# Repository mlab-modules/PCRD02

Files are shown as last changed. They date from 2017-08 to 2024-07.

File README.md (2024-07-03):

# PCRD - Plocs Cosmic Ray Detector

The PCRD is a semiconductor detector for cosmic rays. Its main advantages include sensitivity to all charged particles, low energy consumption, and low weight. Additionally, if the interaction with radiation transfers all its energy to the silicon, it is possible to determine the energy spectrum of the mixed radiation field.

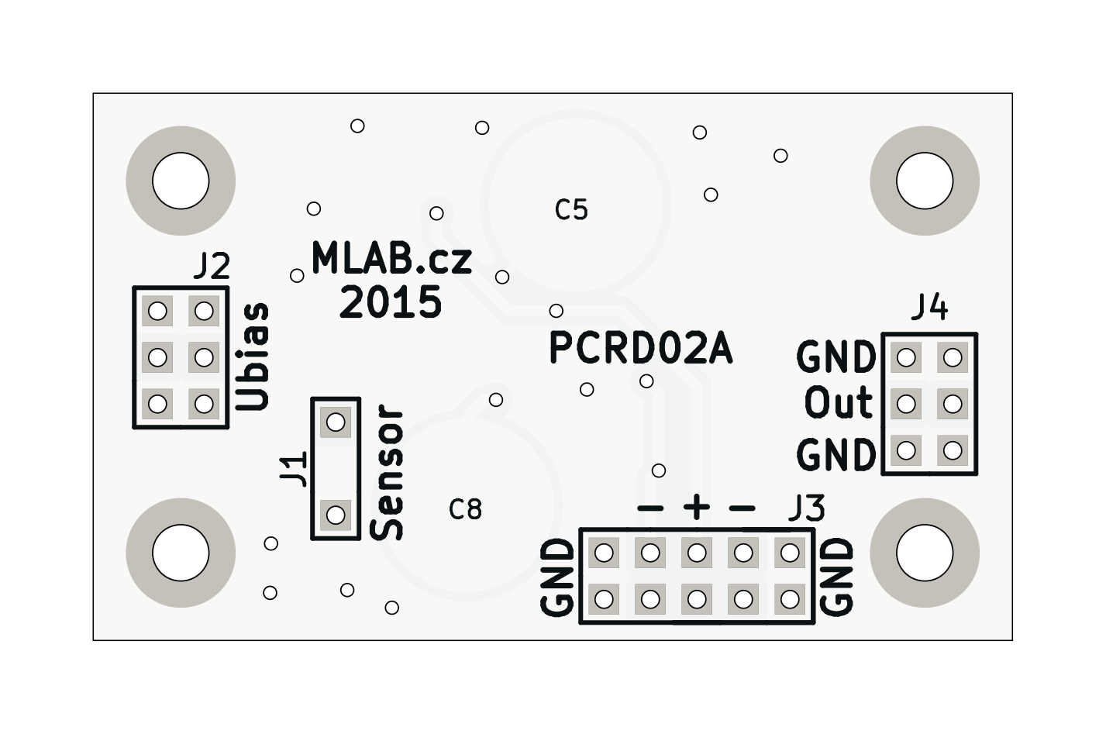
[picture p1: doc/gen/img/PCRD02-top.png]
PCRD02 top
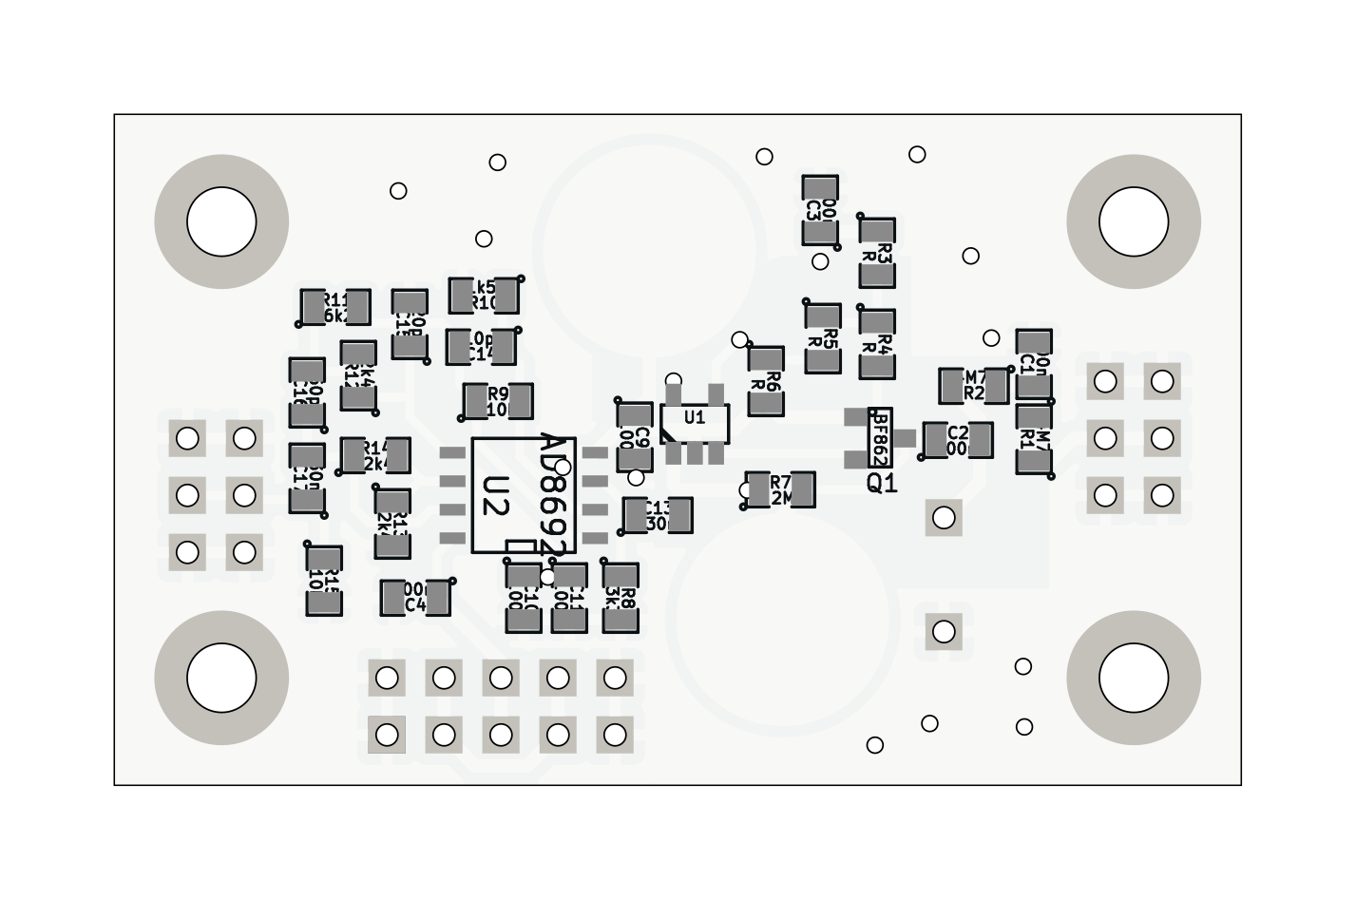
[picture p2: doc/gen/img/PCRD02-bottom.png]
PCRD02 bottom
 

## Technical Parameters

| **Parameter** | **Value** | **Note** |
|---|---|---|
| Power Supply  | +/- 2.4V | |
| Dimensions | 30.0 x 50.3 x 16 mm | Height above base board  |

## Construction Description

### Mechanical Construction

The module contains mounting screws in all corners with an MLAB pitch (10.16mm). If space-saving is needed, the part of the PCB with two screws can be broken off.

## Assembly and Commissioning

### Assembly

| **Designation** | **Type** | **Package** | **Quantity** |
|---|---|---|---|
| R7 | 2M | SMD-0805 | 1 |
| C1, C2 | 100nF | SMD-0805 | 2 |
| C3, C4, C9, C10, C11 | 100n | SMD-0805 | 5 |
| C13, C17 | 330nF | SMD-0805 | 2 |
| C14 | 510pF | SMD-0805 | 1 |
| C15 | 220pF | SMD-0805 | 1 |
| C16 | 150pF | SMD-0805 | 1 |
| J2 | JUMP_3X2 | Pin_Header_Straight_2x03 | 1 |
| J3 | JUMP_5X2 | Pin_Header_Straight_2x05 | 1 |
| J4 | Out | Pin_Header_Straight_2x03 | 1 |
| P1, P2, P3, P4  | _ | MountingHole_3mm | 4 |
| Q1 | BF862 | SOT-23 | 1 |
| R1, R2 | 4M7 | SMD-0805 | 2 |
| R8 | 3k3 | SMD-0805 | 1 |
| R9, R15 | 10k | SMD-0805 | 2 |
| R10 | 1k5 | SMD-0805 | 1 |
| R11 | 6k2 | SMD-0805 | 1 |
| R12, R13, R14 | 2k41k | SMD-0805 | 3 |
| U1 | AD8691 | tsot-5 | 1 |
| J1 | CONN1_2 | CONN_3_2 | 1 |
| U2 | AD8692 | SOIC-8-N | 1 |
| C5, C8 | 2pF | 2pF_PCB | 2 |
| **Variant 1** | | | |
| R3 | 1k | SMD-0805 | 1 |
| R4 | 62 | SMD-0805 | 1 |
| R5 | 100 | SMD-0805 | 1 |
| R6 | 2k | SMD-0805 | 1 |
| **Variant 2** | | | |
| R3 | 1k | SMD-0805 | 1 |
| R4 | 300 | SMD-0805 | 1 |
| R5 | 430 | SMD-0805 | 1 |
| R6 | 1k | SMD-0805 | 1 |

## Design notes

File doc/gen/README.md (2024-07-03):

# PCB

Board size: 50.29x29.97 mm (1.98x1.18 inches)

- This is the size of the rectangle that contains the board
- Thickness: 1.6 mm (63 mils)
- Material: FR4
- Finish: HAL
- Layers: 2
- Copper thickness: 35 µm

Solder mask: TOP / BOTTOM

- Color: Green

Silk screen: TOP / BOTTOM

- Color: White

# Important sizes

Clearance: 0.25 mm (10 mils)

Track width: 0.4 mm (16 mils)

- By design rules: 0.25 mm (10 mils)

Drill: 0.75 mm (30 mils)

- Vias: 0.75 mm (30 mils) [Design: 0.6 mm (24 mils)]
- Pads: 1.0 mm (39 mils)
- The above values are real drill sizes, they add 0.1 mm (4 mils) to plated holes (PTH)

Via: 0.89/0.64 mm (35/25 mils)

- By design rules: 0.89/0.51 mm (35/20 mils)
- Micro via: yes [0.51/0.13 mm (20/5 mils)]
- Buried/blind via: yes
- Total: 18 (thru: 18 buried/blind: 0 micro: 0)

Outer Annular Ring: 0.07 mm (3 mils)

- By design rules: 0.33 mm (13 mils)

Eurocircuits class: 10A
- Using min drill 0.75 mm for an OAR of 0.07 mm

# General stats

Components count: (SMD/THT)

- Top: 0/10 (THT)
- Bottom: 29/1 (SMD + THT)

Defined tracks:

- 0.26 mm (10 mils)
- 0.4 mm (16 mils)
- 0.6 mm (24 mils)

Used tracks:

- 0.4 mm (16 mils) (110) defined: yes
- 0.6 mm (24 mils) (75) defined: yes

Defined vias:

Used vias:

- 0.89/0.64 mm (35/25 mils) (Count: 18, Aspect: 1.8 A) defined: no

Holes (excluding vias):

- 0.9 mm (35 mils) (24)
- 3.0 mm (118 mils) (4)

Oval holes:

Drill tools (including vias and computing adjusts and rounding):

- 0.75 mm (30 mils) (18)
- 1.0 mm (39 mils) (24)
- 3.1 mm (122 mils) (4)

Solder paste stats:

Using a paste with 87.75 % alloy, that has an specific gravity for the alloy of 7.4 g/cm³
and 1.0 g/cm³ for the flux. This paste has an specific gravity of  4.15 g/cm³.

The stencil thickness is  0.12 mm.

| Side | Pads with paste | Area [mm²] | Paste [g] |
|---|---|---|---|
| Total  | 70 | 77.57 | 0.39 |

Note: this is just an approximation to the theoretical value. Margins of the solder mask and waste aren't computed.

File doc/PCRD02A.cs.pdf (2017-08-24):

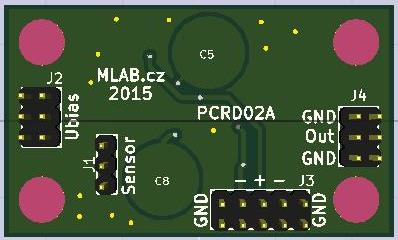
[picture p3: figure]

PCRD02A / 2016-03-09 / jacho/ http://www.mlab.cz | 1 / 5
PCRD02A | MLAB

# Zesilovač pro detektor

## Plocs cosmic ray detector (PCRD)

# 1. Technické parametry

Parametr | Hodnota | Poznámka
Napájení | +/- 2,4 V
Rozměry | 30.0 x 50.3 x 16 mm | Výška nad základní deskou

PCRD02A | MLAB

# 2. Popis konstrukce

## 2.1. Úvodem

## 2.2. Mechanická konstrukce

Modul obsahuje úchytné šroubky ve všech rozích v rozteči MLAB (10.16mm). Při potřebě šetřit místem je možné odlomení části PCB se dvěma šrouby.

PCRD02A | MLAB

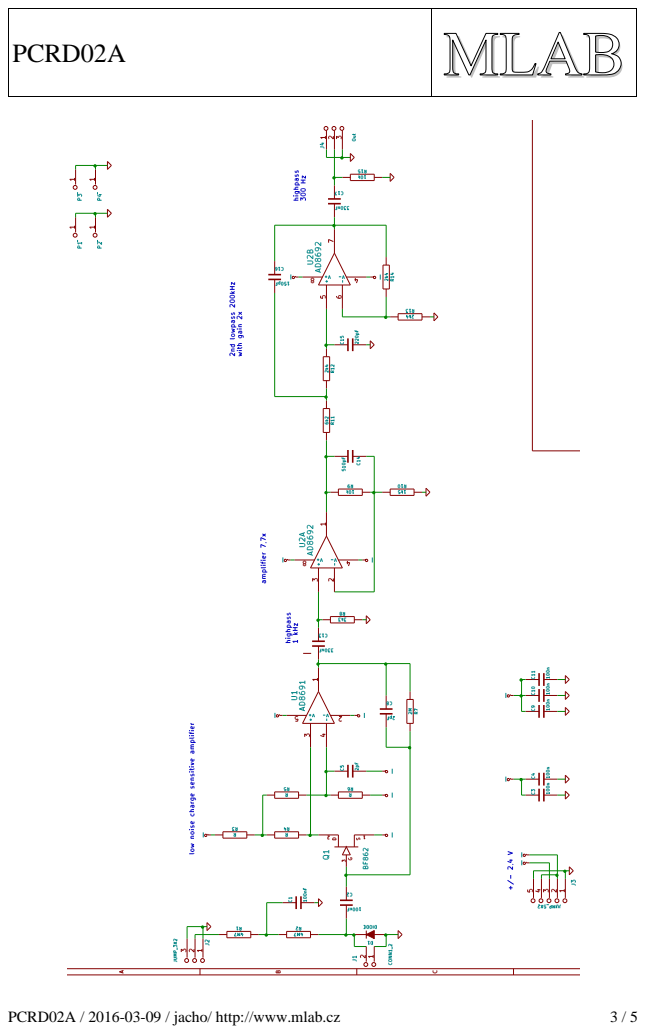
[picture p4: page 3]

PCRD02A | MLAB

# 3. Osazení a oživení

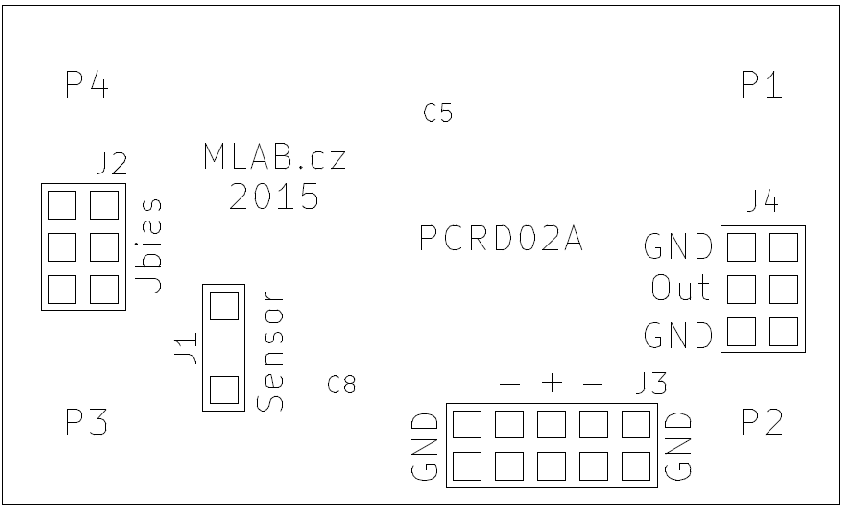
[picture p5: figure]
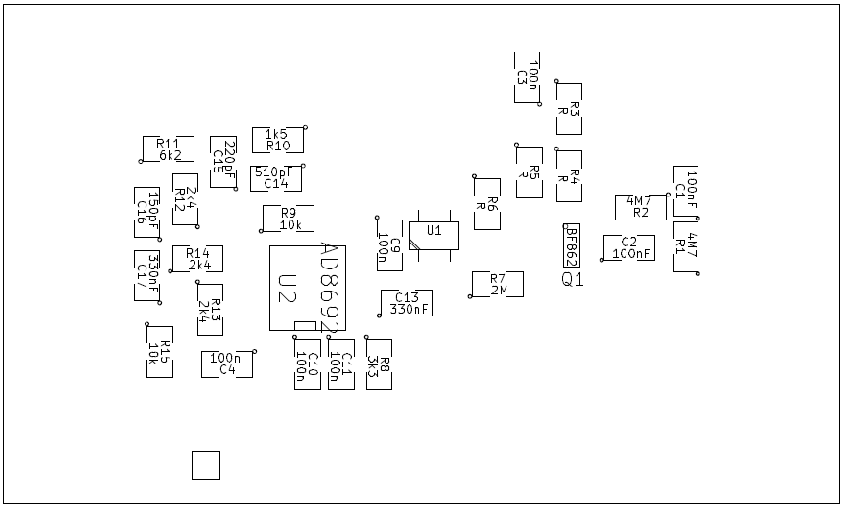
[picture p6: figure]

PCRD02A | MLAB

## 3.1. Osazení

Označení | Typ | Pouzdro | Počet
R7 | 2M | SMD-0805 | 1
C1,C2 | 100nF | SMD-0805 | 2
C3,C4,C9,C10,C11 | 100n | SMD-0805 | 5
C13,C17 | 330nF | SMD-0805 | 2
C14 | 510pF | SMD-0805 | 1
C15 | 220pF | SMD-0805 | 1
C16 | 150pF | SMD-0805 | 1
J2 | JUMP_3X2 | Pin_Header_Straight_2x03 | 1
J3 | JUMP_5X2 | Pin_Header_Straight_2x05 | 1
J4 | Out | Pin_Header_Straight_2x03 | 1
P1,P2,P3,P4 | _ | MountingHole_3mm | 4
Q1 | BF862 | SOT-23 | 1
R1,R2 | 4M7 | SMD-0805 | 2
R8 | 3k3 | SMD-0805 | 1
R9,R15 | 10k | SMD-0805 | 2
R10 | 1k5 | SMD-0805 | 1
R11 | 6k2 | SMD-0805 | 1
R12,R13,R14 | 2k4 | SMD-0805 | 3
U1 | AD8691 | tsot-5 | 1
J1 | CONN1_2 | CONN_3_2 | 1
U2 | AD8692 | SOIC-8-N | 1
C5,C8 | 2pF | 2pF_PCB | 2

Varianta 1
R3 | 1k | SMD-0805 | 1
R4 | 62 | SMD-0805 | 1
R5 | 100 | SMD-0805 | 1
R6 | 2k | SMD-0805 | 1

Varianta 2
R3 | 1k | SMD-0805 | 1
R4 | 300 | SMD-0805 | 1
R5 | 430 | SMD-0805 | 1
R6 | 1k | SMD-0805 | 1

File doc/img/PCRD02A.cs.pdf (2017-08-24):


PCRD02A / 2015-04-02 / jacho/ http://www.mlab.cz | 1 / 5
PCRD02A | MLAB

# Zesilovač pro detektor

## Plocs cosmic ray detector (PCRD)

# 1. Technické parametry

Parametr | Hodnota | Poznámka
Napájení | +/- 2,4 V
Rozměry | 30.0 x 50.3 x 16 mm | Výška nad základní deskou

PCRD02A | MLAB

# 2. Popis konstrukce

## 2.1. Úvodem

## 2.2. Mechanická konstrukce

Modul obsahuje úchytné šroubky ve všech rozích v rozteči MLAB (10.16mm). Při potřebě šetřit místem je možné odlomení části PCB se dvěma šrouby.

PCRD02A | MLAB

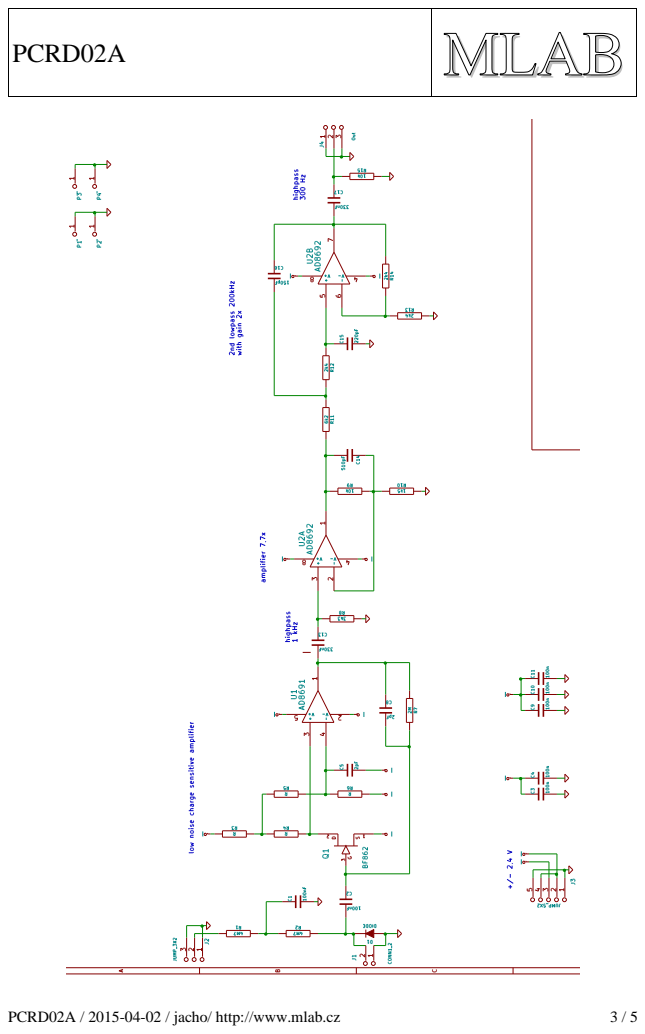
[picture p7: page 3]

PCRD02A | MLAB

# 3. Osazení a oživení

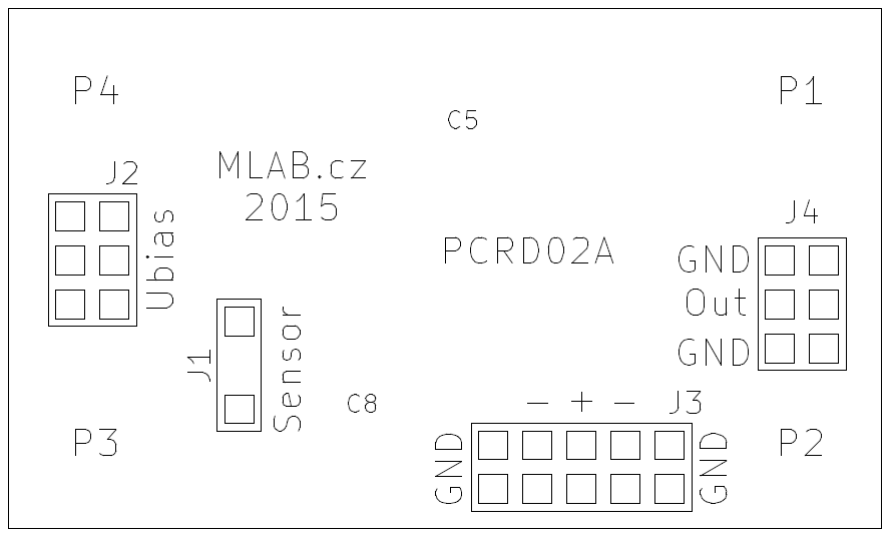
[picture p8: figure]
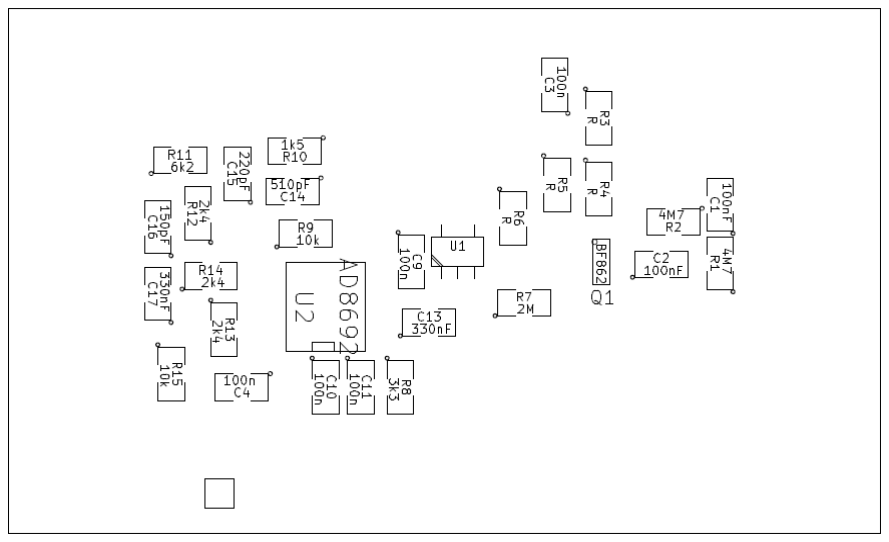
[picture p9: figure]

PCRD02A | MLAB

## 3.1. Osazení

Označení | Typ | Pouzdro | Počet
R7 | 2M | SMD-0805 | 1
C1,C2 | 100nF | SMD-0805 | 2
C3,C4,C9,C10,C11 | 100n | SMD-0805 | 5
C13,C17 | 330nF | SMD-0805 | 2
C14 | 510pF | SMD-0805 | 1
C15 | 220pF | SMD-0805 | 1
C16 | 150pF | SMD-0805 | 1
J2 | JUMP_3X2 | Pin_Header_Straight_2x03 | 1
J3 | JUMP_5X2 | Pin_Header_Straight_2x05 | 1
J4 | Out | Pin_Header_Straight_2x03 | 1
P1,P2,P3,P4 | _ | MountingHole_3mm | 4
Q1 | BF862 | SOT-23 | 1
R1,R2 | 4M7 | SMD-0805 | 2
R8 | 3k3 | SMD-0805 | 1
R9,R15 | 10k | SMD-0805 | 2
R10 | 1k5 | SMD-0805 | 1
R11 | 6k2 | SMD-0805 | 1
R12,R13,R14 | 2k4 | SMD-0805 | 3
U1 | AD8691 | tsot-5 | 1
J1 | CONN1_2 | CONN_3_2 | 1
U2 | AD8692 | SOIC-8-N | 1
C5,C8 | 2pF | 2pF_PCB | 2

Varianta 1
R3 | 1k | SMD-0805 | 1
R4 | 62 | SMD-0805 | 1
R5 | 100 | SMD-0805 | 1
R6 | 2k | SMD-0805 | 1

Varianta 2
R3 | 1k | SMD-0805 | 1
R4 | 300 | SMD-0805 | 1
R5 | 430 | SMD-0805 | 1
R6 | 1k | SMD-0805 | 1

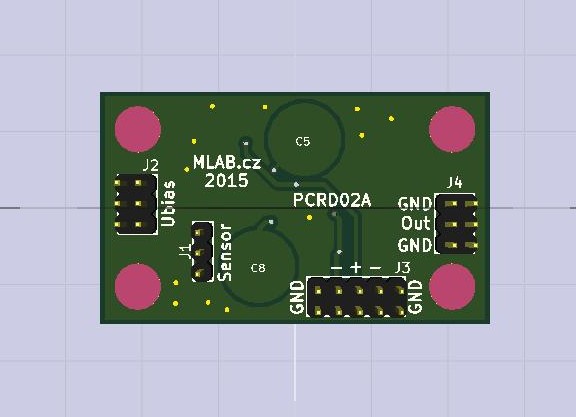
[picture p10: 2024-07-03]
doc/img/PCRD02A_top_small.jpg

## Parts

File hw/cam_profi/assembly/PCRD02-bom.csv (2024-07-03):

Component | Description | Part | References | Value | Footprint | Quantity Per PCB | Datasheet
1 |  | C | C5C8 | 2pF | C2pF | 2
2 |  | C | C16 | 150pF | SMD-0805 | 1
3 |  | C | C15 | 220pF | SMD-0805 | 1
4 |  | C | C14 | 510pF | SMD-0805 | 1
5 |  | C | C1C2C3C4C9C10C11 | 100nF | SMD-0805 | 7
6 |  | C | C13C17 | 330nF | SMD-0805 | 2
7 |  | DIODE | D1 | DIODE |  | 1
8 |  | CONN1_2 | J1 | CONN1_2 | CONN_3_2 | 1
9 |  | JUMP_3X2 | J2 | JUMP_3X2 | Pin_Header_Straight_2x03 | 1
10 |  | JUMP_5X2 | J3 | JUMP_5X2 | Pin_Header_Straight_2x05 | 1
11 |  | JUMP_3X2 | J4 | Out | Pin_Header_Straight_2x03 | 1
12 |  | JFET_N | Q1 | BF862 | SOT-23 | 1
13 |  | R | R10 | 1k5 | SMD-0805 | 1
14 |  | R | R12R13R14 | 2k4 | SMD-0805 | 3
15 |  | R | R8 | 3k3 | SMD-0805 | 1
16 |  | R | R11 | 6k2 | SMD-0805 | 1
17 |  | R | R9R15 | 10k | SMD-0805 | 2
18 |  | R | R7 | 2M | SMD-0805 | 1
19 |  | R | R1R2 | 4M7 | SMD-0805 | 2
20 |  | R | R3R4R5R6 | R | SMD-0805 | 4
21 |  | AD8691 | U1 | AD8691 | tsot-5 | 1
22 |  | AD8692 | U2 | AD8692 | SOIC-8-N | 1

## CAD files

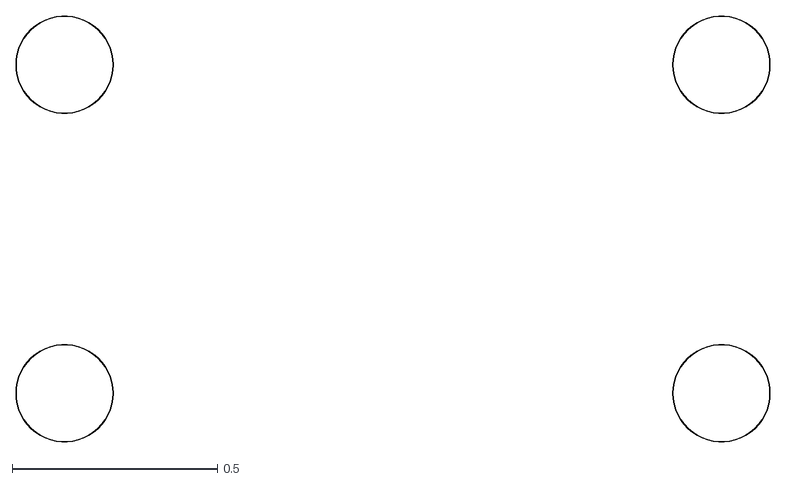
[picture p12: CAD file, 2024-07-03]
doc/gen/dxf/PCRD02-F_Adhesive.dxf
1.84 x 1.04

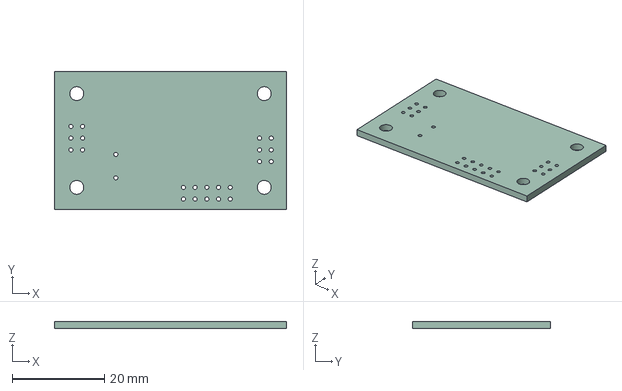
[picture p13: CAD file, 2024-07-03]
doc/gen/PCRD02.step
50.3 x 30.0 x 1.60 mm

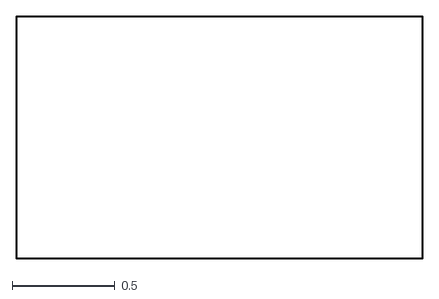
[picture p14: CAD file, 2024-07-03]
doc/gen/dxf/PCRD02-Edge_Cuts.dxf
1.98 x 1.18

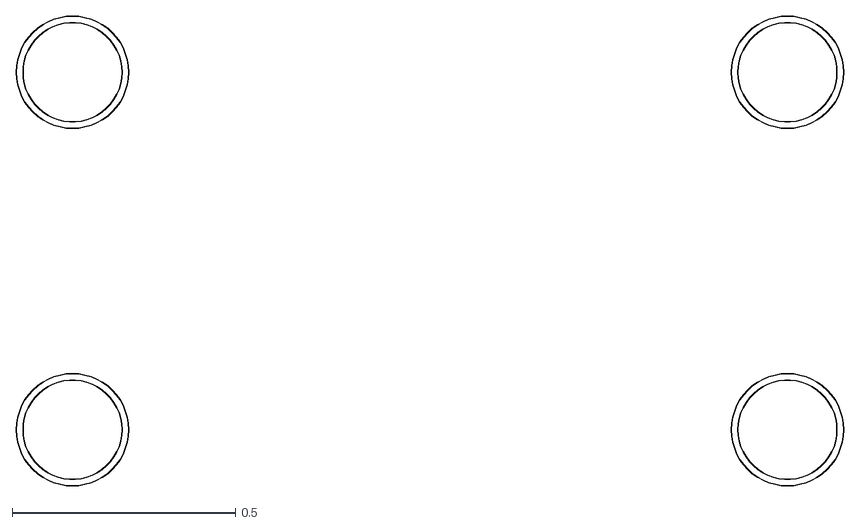
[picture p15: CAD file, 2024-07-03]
doc/gen/dxf/PCRD02-User_Comments.dxf
1.85 x 1.05

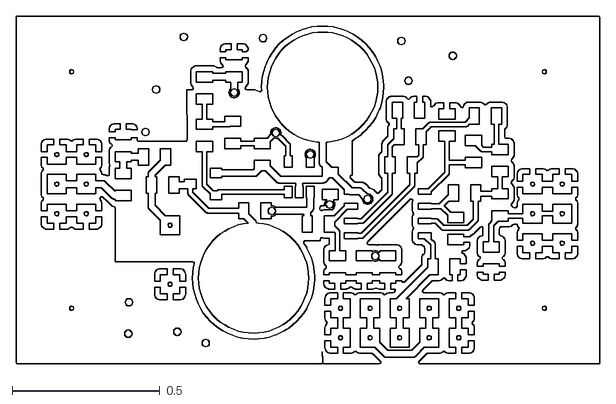
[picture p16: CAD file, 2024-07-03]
doc/gen/dxf/PCRD02-B_Cu.dxf
1.98 x 1.18

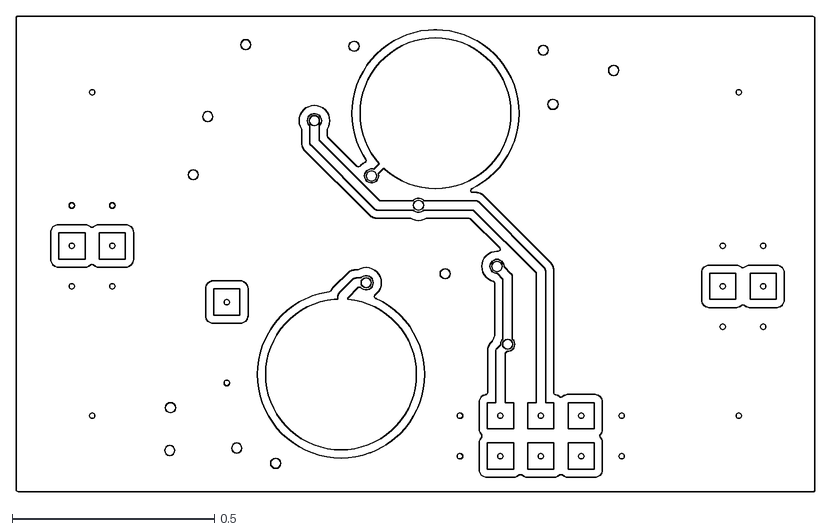
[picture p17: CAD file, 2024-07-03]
doc/gen/dxf/PCRD02-F_Cu.dxf
1.98 x 1.18

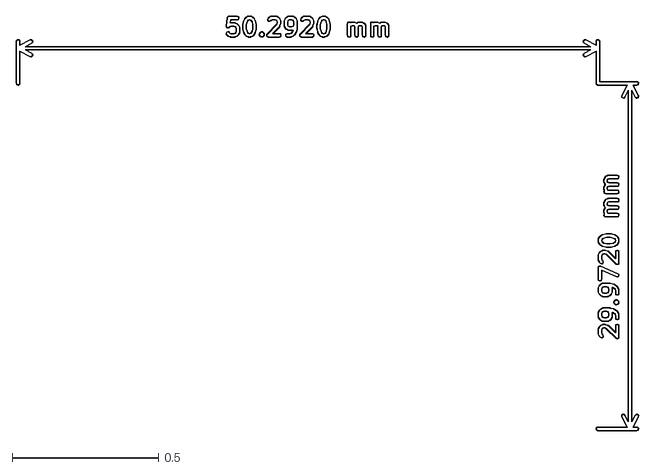
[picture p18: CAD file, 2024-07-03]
doc/gen/dxf/PCRD02-User_Drawings.dxf
2.12 x 1.42

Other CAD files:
doc/gen/dxf/PCRD02-F_Fab.dxf
doc/gen/dxf/PCRD02-Margin.dxf
doc/gen/dxf/PCRD02-F_Courtyard.dxf
doc/gen/dxf/PCRD02-B_Fab.dxf
doc/gen/dxf/PCRD02-User_Eco2.dxf
doc/gen/dxf/PCRD02-User_Eco1.dxf
doc/gen/dxf/PCRD02-B_Courtyard.dxf
doc/gen/dxf/PCRD02-B_Mask.dxf
doc/gen/dxf/PCRD02-B_Paste.dxf
doc/gen/dxf/PCRD02-B_Silkscreen.dxf
doc/gen/dxf/PCRD02-F_Mask.dxf
doc/gen/dxf/PCRD02-F_Paste.dxf
doc/gen/dxf/PCRD02-F_Silkscreen.dxf

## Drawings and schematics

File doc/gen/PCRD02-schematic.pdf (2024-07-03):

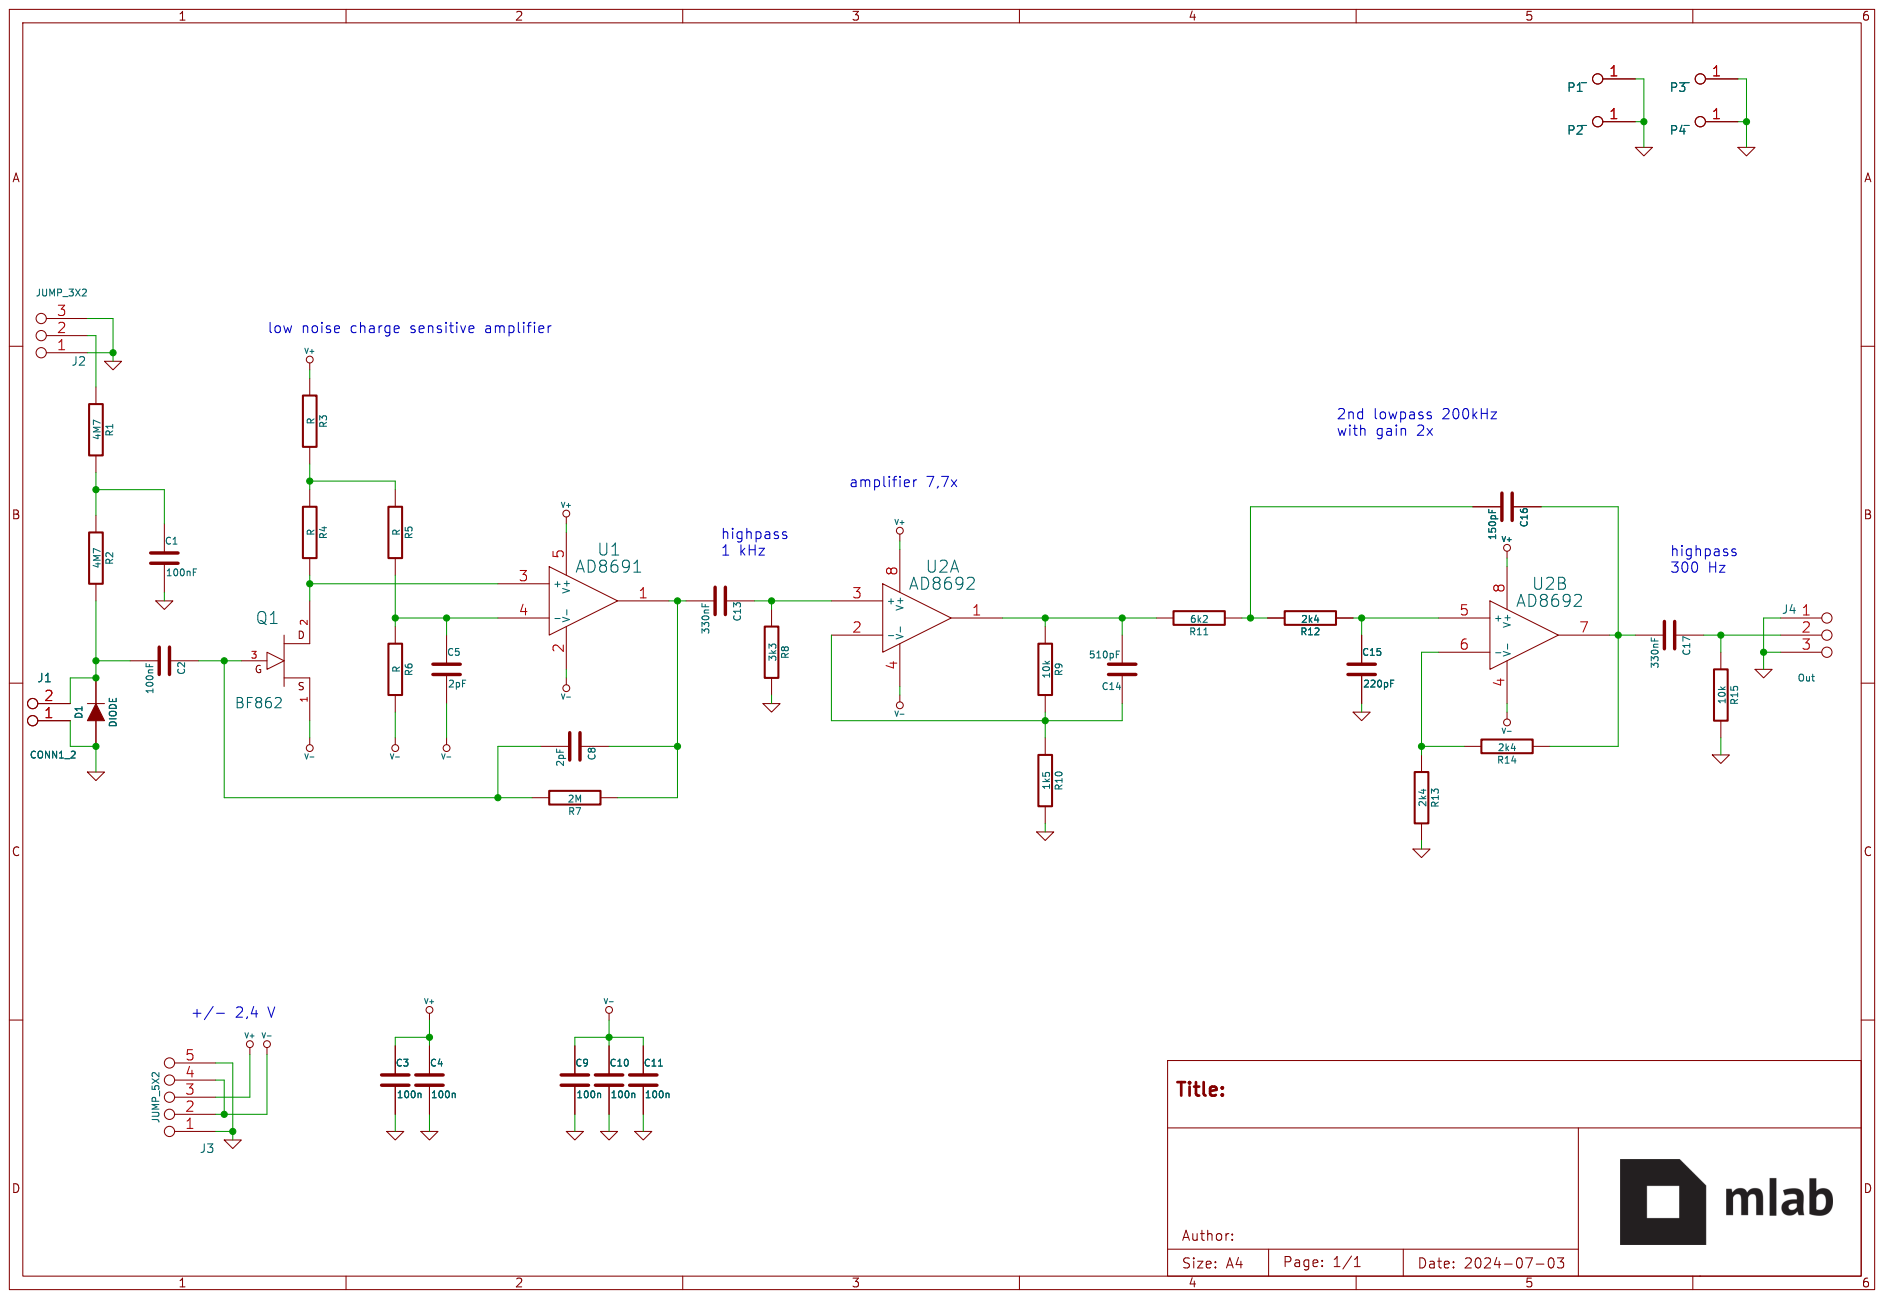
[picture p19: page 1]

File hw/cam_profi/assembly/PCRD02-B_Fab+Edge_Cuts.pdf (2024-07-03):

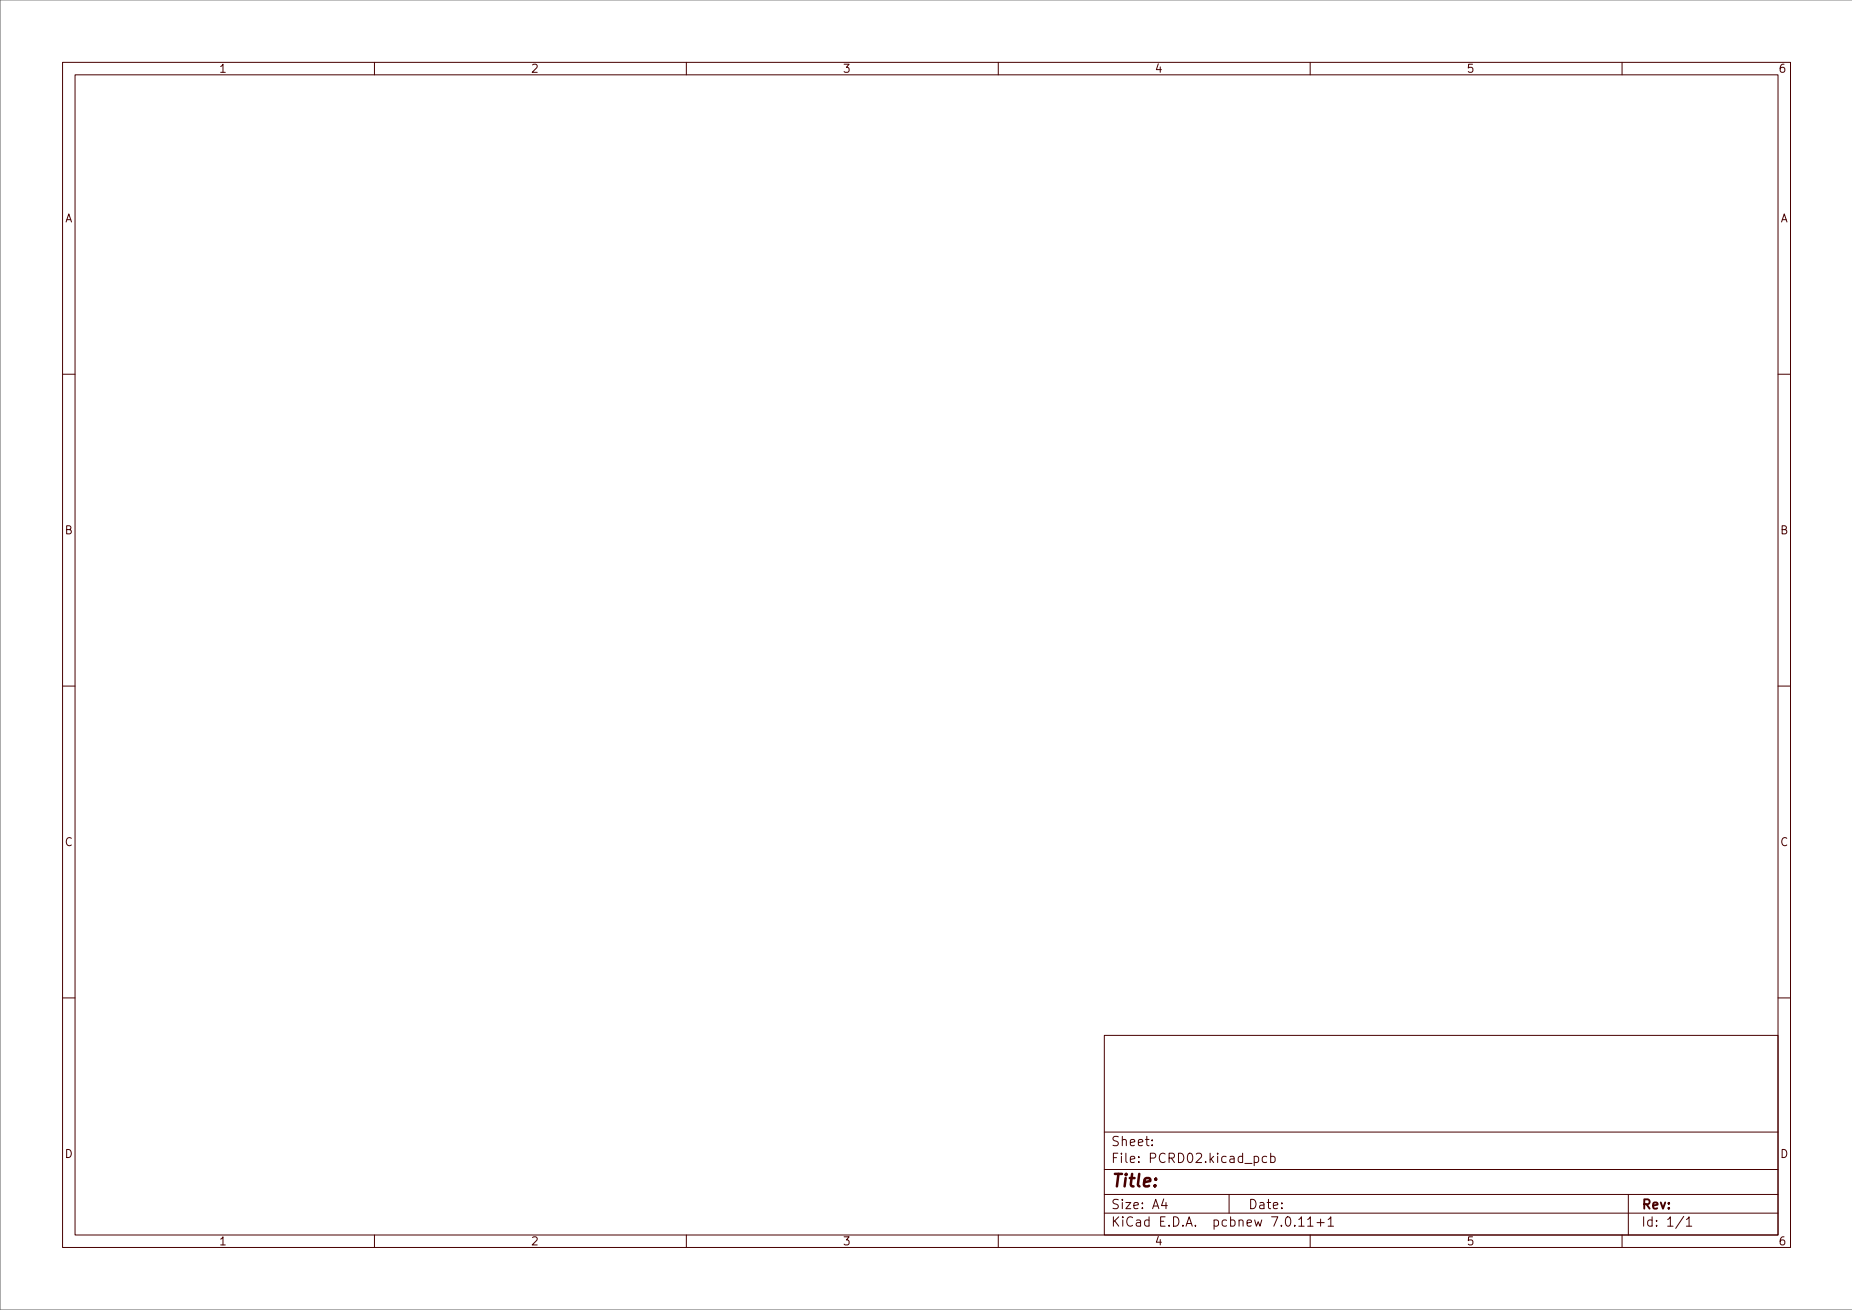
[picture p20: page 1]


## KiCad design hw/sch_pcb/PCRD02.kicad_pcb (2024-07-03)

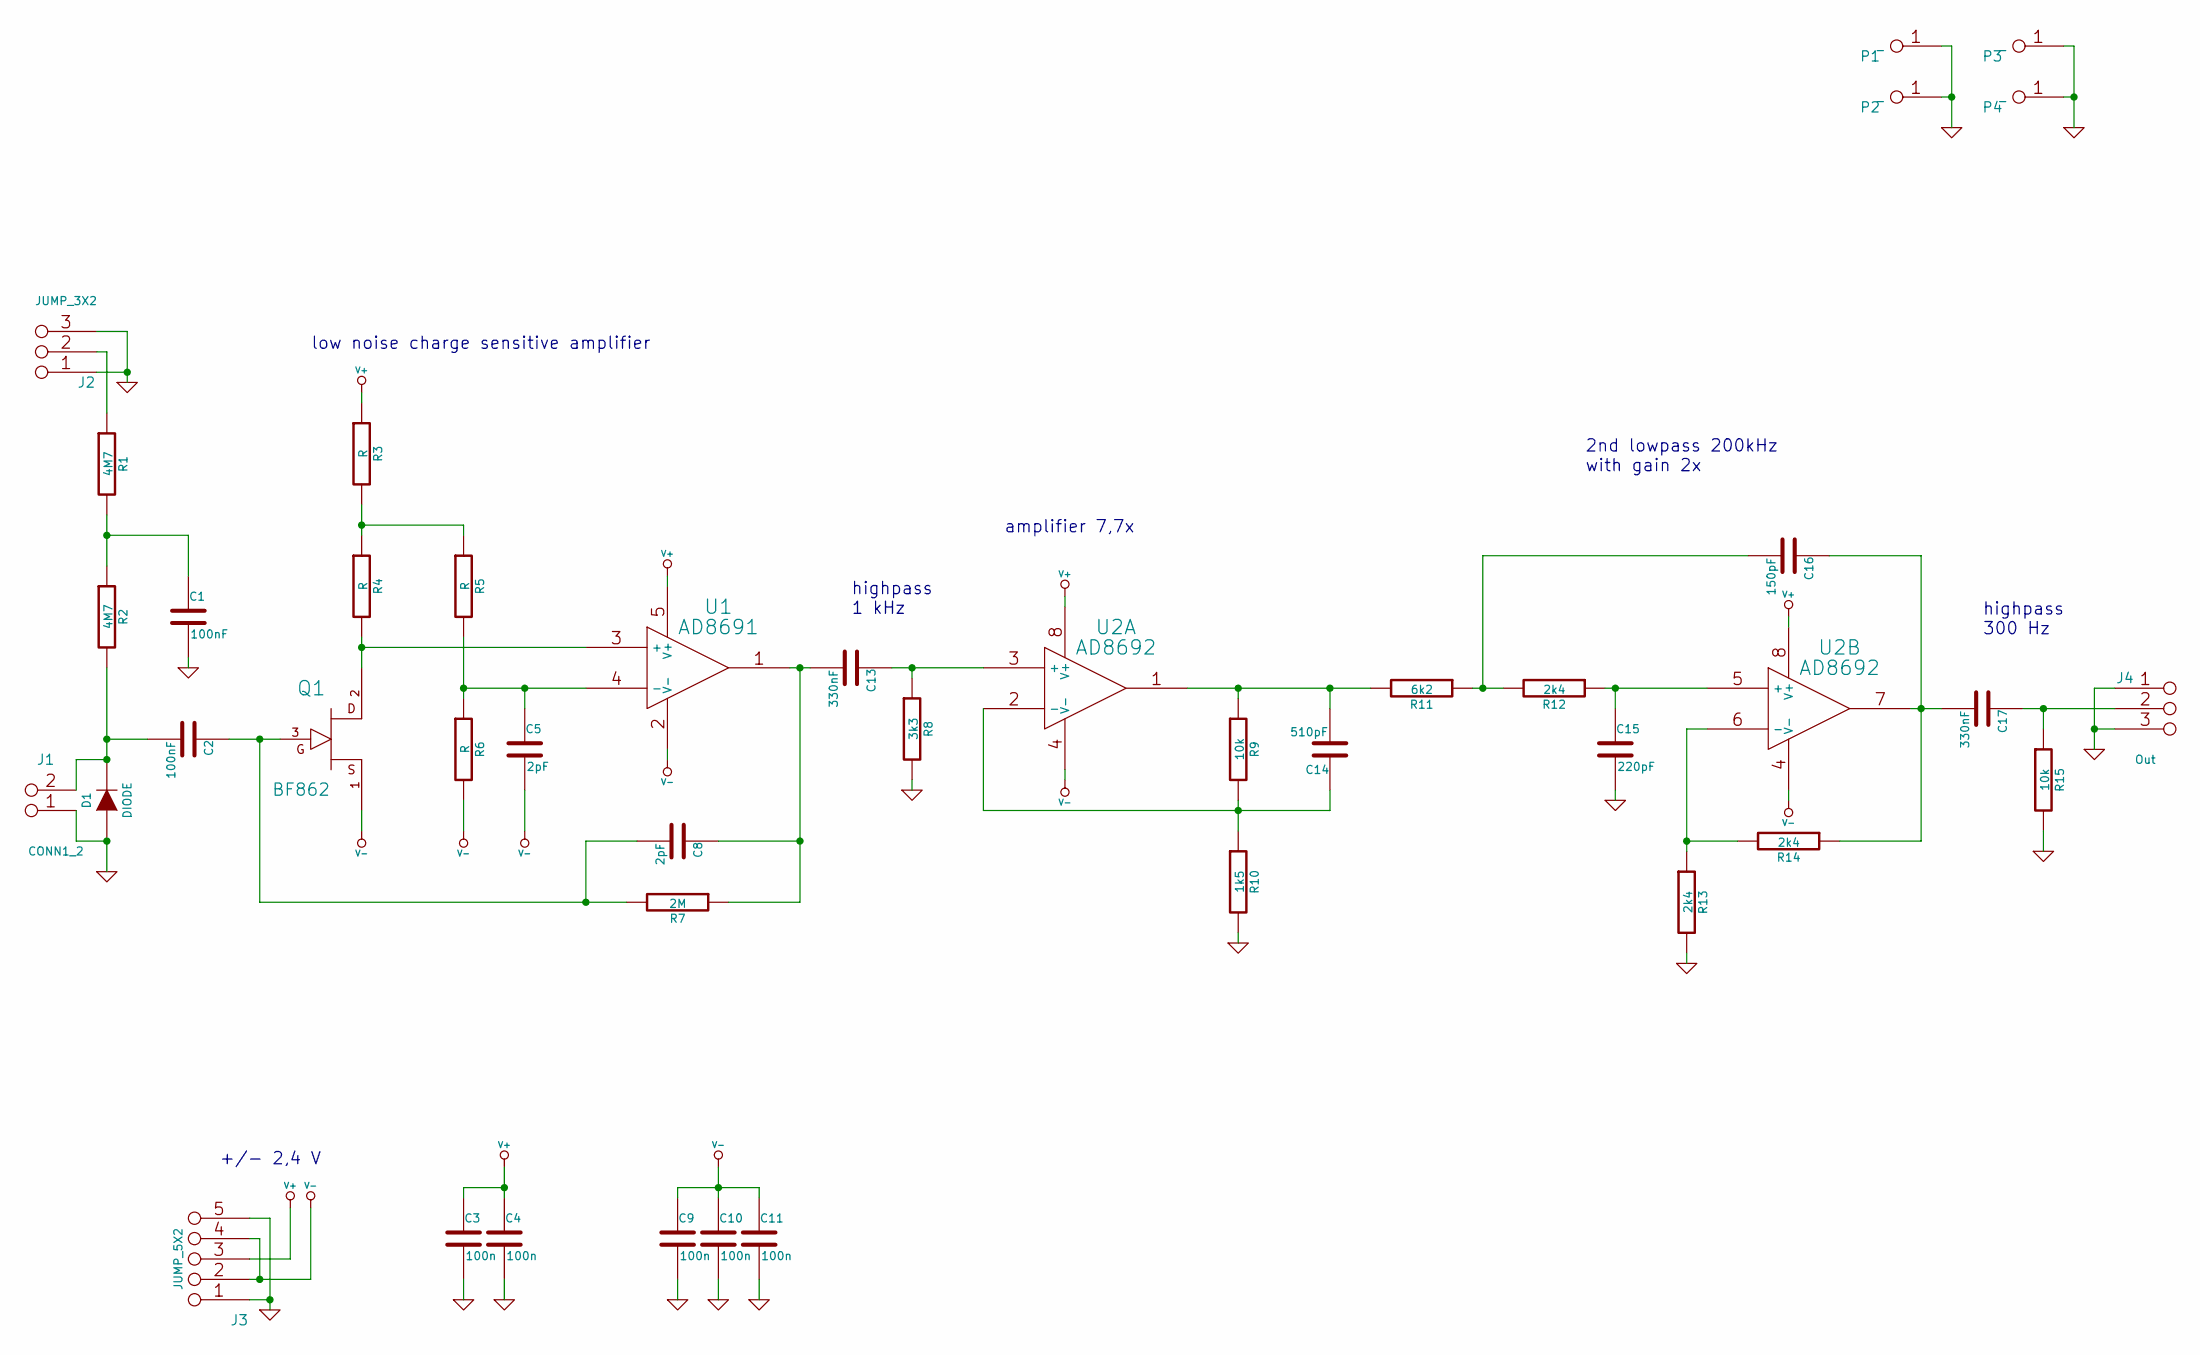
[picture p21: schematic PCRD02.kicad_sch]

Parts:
C1, C2: 100nF; SMD-0805
C3, C4, C9, C10, C11: 100n; SMD-0805
C5, C8: 2pF; C2pF
C13, C17: 330nF; SMD-0805
C14: 510pF; SMD-0805
C15: 220pF; SMD-0805
C16: 150pF; SMD-0805
D1: DIODE
J1: CONN1_2; CONN_3_2
J2: JUMP_3X2; Pin_Header_Straight_2x03
J3: JUMP_5X2; Pin_Header_Straight_2x05
J4: Out; Pin_Header_Straight_2x03
P1, P2, P3, P4: _; MountingHole_3mm
Q1: BF862; SOT-23
R1, R2: 4M7; SMD-0805
R3, R4, R5, R6: R; SMD-0805
R7: 2M; SMD-0805
R8: 3k3; SMD-0805
R9, R15: 10k; SMD-0805
R10: 1k5; SMD-0805
R11: 6k2; SMD-0805
R12, R13, R14: 2k4; SMD-0805
U1: AD8691; tsot-5
U2: AD8692; SOIC-8-N

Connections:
GND: C1.2, C3.2, C4.2, C9.2, C10.2, C11.2, C15.2, D1.1 (A), J1.1, J2.1, J2.3, J2.4, J2.6, J3.1, J3.5, J3.6, J3.10, J4.1, J4.3, J4.4, J4.6, P1.1, P2.1, P3.1, P4.1, R8.2, R10.2, R13.2, R15.2
unnamed: C1.1, R1.2, R2.1
unnamed: C2.1, C8.2, Q1.3 (G), R7.2
unnamed: C2.2, D1.2 (K), J1.2 (PM), R2.2
unnamed: C5.1, R5.2, R6.1, U1.4 (-)
unnamed: C13.1, R8.1, U2.3 (+)
unnamed: C8.1, C13.2, R7.1, U1.1
unnamed: C14.1, R9.2, R10.1, U2.2 (-)
unnamed: C14.2, R9.1, R11.2, U2.1
unnamed: C15.1, R12.1, U2.5 (+)
unnamed: C16.1, C17.2, R14.1, U2.7
unnamed: C16.2, R11.1, R12.2
unnamed: C17.1, J4.2 (1), J4.5, R15.1
unnamed: J2.2 (1), J2.5, R1.1
unnamed: Q1.2 (D), R4.2, U1.3 (+)
unnamed: R3.2, R4.1, R5.1
unnamed: R13.1, R14.2, U2.6 (-)
V+: C3.1, C4.1, J3.3, J3.8, R3.1, U1.5 (V+), U2.8 (V+)
V-: C5.2, C9.1, C10.1, C11.1, J3.2, J3.4, J3.7, J3.9, Q1.1 (S), R6.2, U1.2 (V-), U2.4 (V-)

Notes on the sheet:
2nd lowpass 200kHz with gain 2x
amplifier 7,7x
highpass 300 Hz
+/- 2,4 V
low noise charge sensitive amplifier
highpass 1 kHz

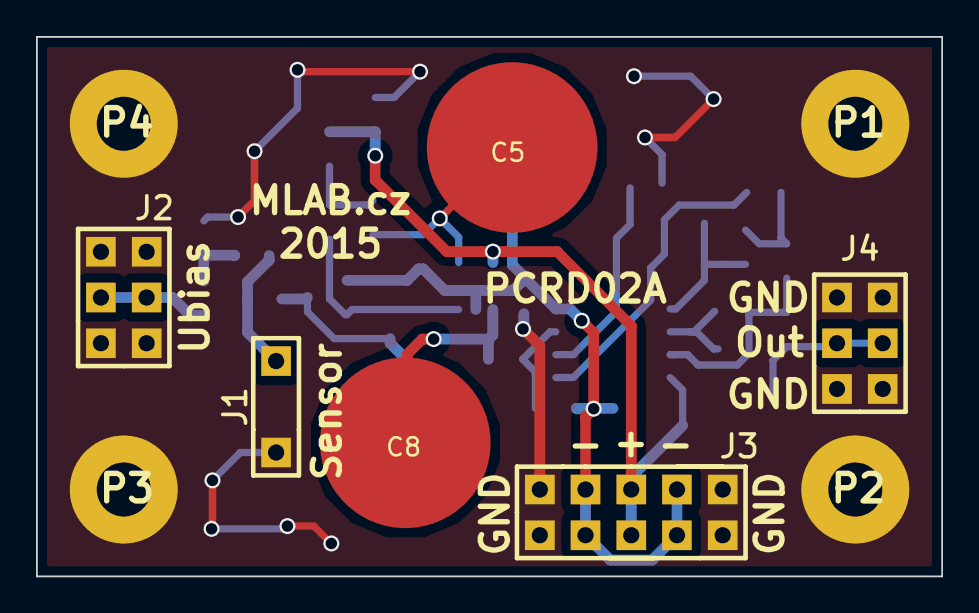
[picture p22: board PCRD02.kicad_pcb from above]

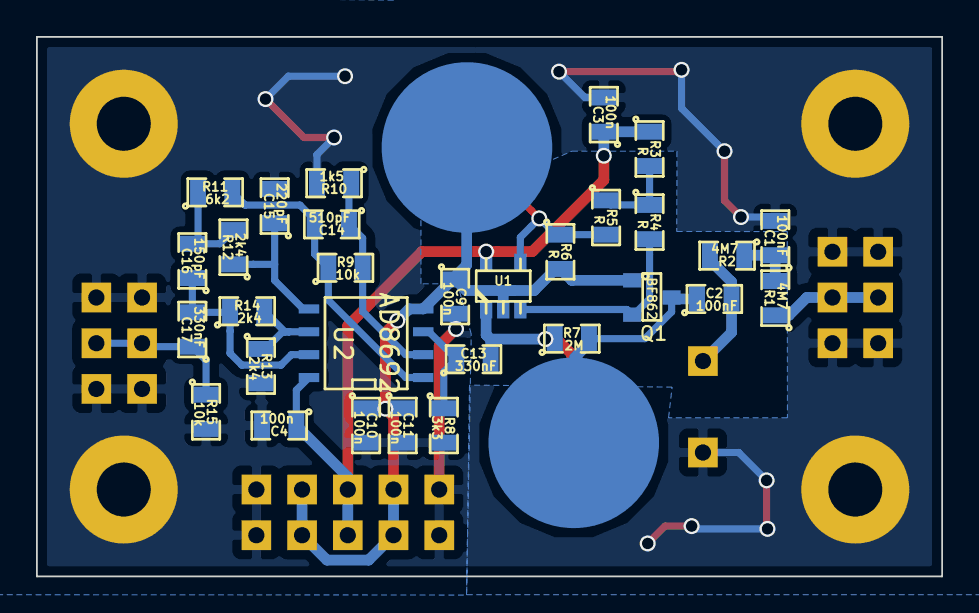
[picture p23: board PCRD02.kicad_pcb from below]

Board: 2 copper layers, 50.3 x 30.0 mm, 40 parts (30 on the bottom side), 19 nets.

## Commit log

2017-08-24 Microcontrollers and processors moved to separate directory.
    [PCRD02A.kicad_pcb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]
2022-04-06 Update actions products
    [PCRD02A-B_Cu.gbr, PCRD02A-B_Mask.gbr, PCRD02A-Edge_Cuts.gbr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]
2023-07-05 automated commit; rename source files to new naming convence
    [PCRD02.kicad_pcb]
2024-07-03 Update project names.
    [PCRD02.sch]
2024-07-03 Update project to KiCADv7, crop the title image.
    [PCRD02.kicad_pcb, PCRD02.kicad_sch, PCRD02.sch]
